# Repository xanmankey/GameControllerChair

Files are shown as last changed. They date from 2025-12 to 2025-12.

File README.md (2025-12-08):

# "Gaming" Chair

So we decided to build a gaming chair... and by that we mean a chair that you can use to play video games!

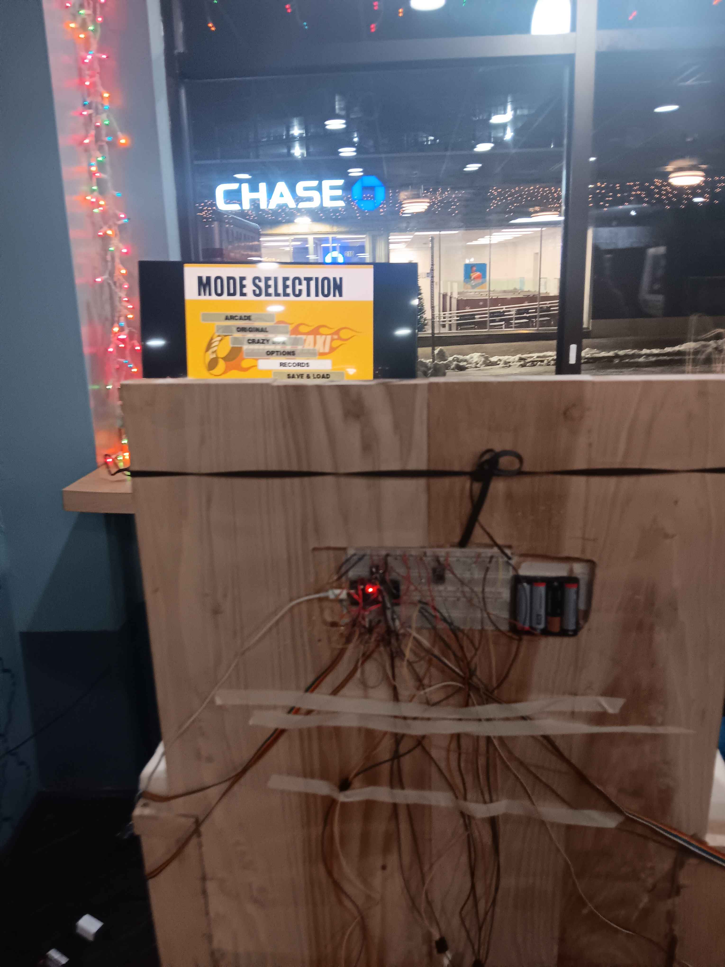
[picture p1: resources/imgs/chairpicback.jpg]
Back of the chair, set up to play Crazy Taxi


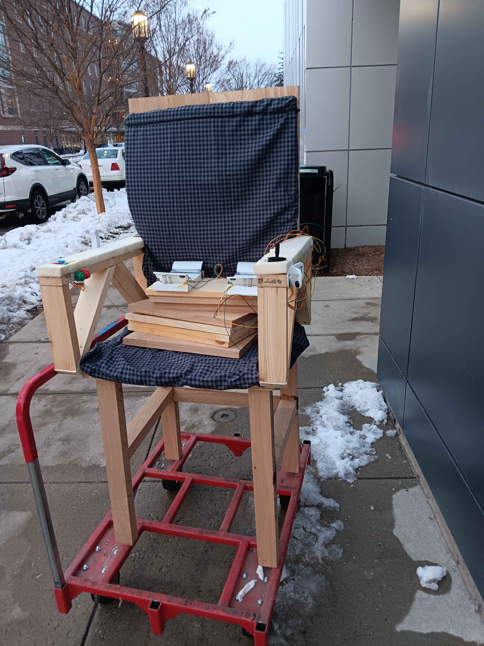
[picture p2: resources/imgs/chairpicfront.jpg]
Front of the chair; we will definitely be installing wheels, the cart was NOT the play


Below you can find a quick writeup on the components of our chair, as well as the BOM in case you want to build a "gaming" chair yourself or adapt an existing chair into one.

## Woods

Our chair is 29.5" x 23.5" x 57"; it's more of a gaming THRONE than a chair now that I think about it.

For the legs, we fashioned 7 pieces of about 2.5" x 2" x 24" and cut down 3 of them, domino jointing and woodgluing them horizontally to the other 4 legs for support (we left the front open so a wood support piece wouldn't interfere with dangling legs).

For the seat (22" x 21.5" x 1") and the back (24" x 1" x 32") we lucked out and happened to find pieces that mostly fit; we just had to do a bit of woodgluing and planing.

For the arms, the goal was to make triangle supports and domino joint/glue them to the back so that the triangle joints could be glued down to the seat for extra support; we mismeasured and so we had to make extension pieces to the side of the seat to provide extra support for the arms.

For placing the electronics, we drilled holes for the wires, chiseled out a place for the joystick (left arm) and buttons (right arm) and hand-routed into the back of the chair for a place for all the electronics.

## 3D Designs

There are currently 3 primary 3D designs that we used:

- The start lever
- [Left and right triggers](resources/models/TriggerButtons.f3d)
- [The foot pedals](resources/models/FootPedal.f3d)

Those designs can be found in the `resources/models` directory.

We also tried to make a box for cable management, but it didn't fit on the build plate of any of the printers that we had access to and so we ended up with a chair that 29 people (and counting) have said looks like an electric chair.

## Fabrics

We started to do upholstery, but ultimately decided to scrap it before the Purdue Hackers showcase due to time constraints; instead, we wrapped our foam and sewed in velcro, as well as stapling velcro to the back and the seat so the foam cushioning could be attached.

## Electrical

We bought a bunch of braided ribbon cable for the project; while this was good in terms of flexibility, it made soldering and wiring a bit of a nightmare. I've lost count of the number of solder joints that have broken at this point (mostly due to transport). We used an ESP32 microcontroller for the controller itself, analog hall effect sensors rigged with magnets that move closer to the sensor for the triggers and footpedals, and just attached the wires opposite each other for the start lever so they contact on pulling the lever. We battery-powered all the sensors which is probably unnecessary (you can probably get away with using 3v3V and stepping it up to 5V using a booster), but it's kinda funny so we kept it.

In terms of the electrical components we ended up using:

- Arcade buttons: https://a.co/d/8YRFZ9m
- Analog hall effect sensors: https://a.co/d/5u7OO93
- ESP32 microcontroller: https://a.co/d/g4PPseC
- Analog joystick: https://www.adafruit.com/product/3102
- Miniboost: https://www.adafruit.com/product/4654
- 6x Magnets: https://www.adafruit.com/product/9

## Programming

We were initially going to be using Bluetooth, but realized that there wasn't any point with all the wires we had anyway and so we migrated to communicating over USB serial (src/main.cpp) with a python script (src/controller.py) that uses the vgamepad library to emulate an xbox360 controller.

## Next Steps

We have commitments from people to play Dark Souls, Celeste, Cuphead, Silksong and various other games with the chair, so we want to make sure it's a polished gameplay experience. We plan on reworking the pedals, since the current solution has too much spring tension and is awkward to rest your feet on, as well as cleaning up some of the electrical and either upholstering or spray painting the chair (some kind of design work).

## Contributions

Thanks to @Benjamin for his help with the woodworking and electronics, to @Soham for his help with the electronics and 3D design and to @Grace for her help with soldering. Huge thank you to @PurdueHackers for funding this project and for organizing an awesome event for us to show it off and to @BechtelInnovationDesignCenter for helping us with woods and electronics and allowing us to borrow the tools needed to make this project a reality.

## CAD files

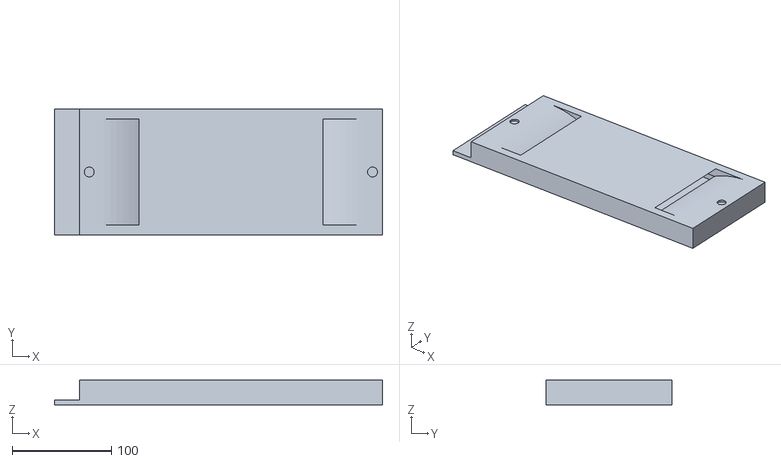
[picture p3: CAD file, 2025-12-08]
resources/models/PedalBase.stl
329.8 x 127.0 x 25.0

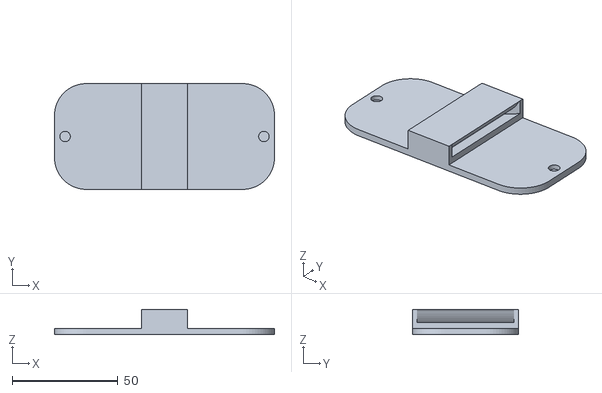
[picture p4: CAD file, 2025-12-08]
resources/models/TriggerBody.stl
104.0 x 50.0 x 12.0

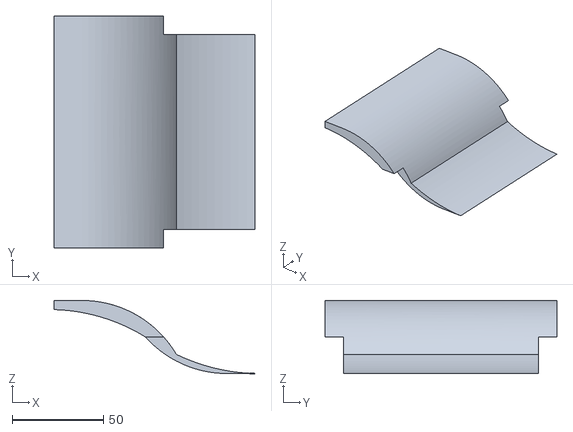
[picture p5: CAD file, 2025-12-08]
resources/models/MinusPedal.stl
109.9 x 127.0 x 40.0

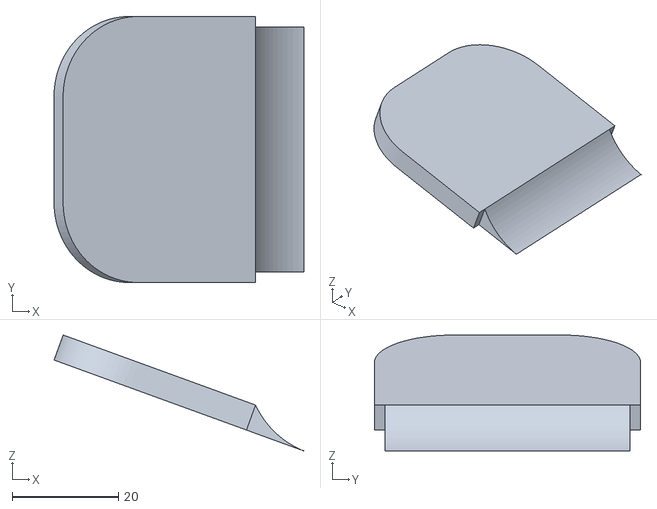
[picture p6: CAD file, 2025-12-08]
resources/models/LT.stl
47.0 x 50.0 x 21.8

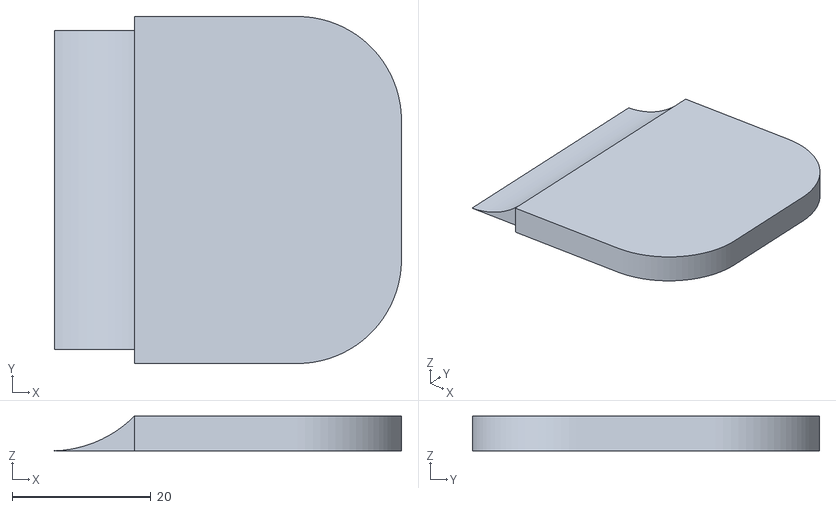
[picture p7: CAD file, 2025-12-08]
resources/models/RT.stl
50.0 x 50.0 x 5.00

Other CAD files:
resources/models/PlusPedal.stl
resources/models/FootPedal.f3d
resources/models/TriggerButtons.f3d

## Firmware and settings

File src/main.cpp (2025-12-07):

#include <Arduino.h>

// =======================
// PIN DEFINITIONS
// =======================
#define A GPIO_NUM_18
#define B GPIO_NUM_19
#define X GPIO_NUM_22
#define Y GPIO_NUM_23
#define LB GPIO_NUM_27
#define RB GPIO_NUM_4
#define START GPIO_NUM_21 

#define PEDAL_UP    GPIO_NUM_26
#define PEDAL_DOWN  GPIO_NUM_25
#define PEDAL_LEFT  GPIO_NUM_36 // was 14, changed due to weird analog glitch with lb and rb
#define PEDAL_RIGHT GPIO_NUM_32

#define CSTICK_X    GPIO_NUM_15 
#define CSTICK_Y    GPIO_NUM_33

#define LT GPIO_NUM_34
#define RT GPIO_NUM_35

// =======================
// CALIBRATION (Adjusted for Feet-On-Pedals)
// =======================

// --- PEDAL RIGHT (Active Low) ---
// Log: Rest ~1822, Max Press ~1703. Short range (~120).
// Drift seen: Positive 0.25 (meaning value dropped below 1800).
// New Rest: 1760 (Pushing threshold lower to ignore foot weight)
#define RIGHT_REST 1760 
#define RIGHT_MAX  1710 

// --- PEDAL LEFT (Active High) ---
// Log: Rest ~2080.
// New Rest: 2200 (Raised to ignore foot weight)
#define LEFT_REST 2200  
#define LEFT_MAX  2800

// --- PEDAL UP (Active High) ---
// Log: Rest ~1983.
// New Rest: 2100 (Raised to ignore foot weight)
#define UP_REST   2050  
#define UP_MAX    2400  

// --- PEDAL DOWN (Active High) ---
// Log: Rest ~1920.
// Drift seen: Negative 0.08 (meaning value went above 2000).
// New Rest: 2100 (Raised to ignore foot weight)
#define DOWN_REST 2050  
#define DOWN_MAX  2400

// --- JOYSTICK & TRIGGERS ---
#define JOY_CENTER 1850 
#define JOY_DEADZONE 250
#define JOY_MIN 0
#define JOY_MAX 4095

#define LT_MIN 2160  
#define LT_MAX 2750
#define RT_MIN 2160
#define RT_MAX 2800

#define TARGET_MAX 255

// =======================
// VARIABLES
// =======================
unsigned long lastLoopTime = 0;
const int loopInterval = 10; 
int prevStartReading = -1;       
bool virtualStartButtonState = false; 
unsigned long startButtonTimer = 0;   
const int startButtonDuration = 100;  

void setup() {
  Serial.begin(115200);

  // Buttons
  pinMode(A, INPUT_PULLDOWN);
  pinMode(B, INPUT_PULLDOWN);
  pinMode(X, INPUT_PULLDOWN);
  pinMode(Y, INPUT_PULLDOWN);
  pinMode(LB, INPUT_PULLDOWN);
  pinMode(RB, INPUT_PULLDOWN);
  pinMode(START, INPUT_PULLDOWN);

  // Pedals
  pinMode(PEDAL_UP, INPUT);
  pinMode(PEDAL_DOWN, INPUT);
  pinMode(PEDAL_LEFT, INPUT);
  pinMode(PEDAL_RIGHT, INPUT);

  // C-Stick & Triggers
  pinMode(CSTICK_X, INPUT);
  pinMode(CSTICK_Y, INPUT);
  pinMode(LT, INPUT);
  pinMode(RT, INPUT);
}

// Helper: Active High Mapping (Value goes UP)
int mapActiveHigh(int val, int rest, int max_val) {
    if (val < rest) return 0; // Deadzone
    int mapped = map(val, rest, max_val, 0, 127);
    return constrain(mapped, 0, 127);
}

// Helper: Active Low Mapping (Value goes DOWN) - Specifically for Right Pedal
int mapActiveLow(int val, int rest, int max_val) {
    if (val > rest) return 0; // Deadzone (Value is higher than threshold)
    // Map from Rest(High) -> Max(Low) to 0 -> 127
    int mapped = map(val, rest, max_val, 0, 127);
    return constrain(mapped, 0, 127);
}

int mapJoystick(int val) {
    int centered = val - JOY_CENTER;
    if (abs(centered) < JOY_DEADZONE) return 0;
    int result = 0;
    if (centered > 0) result = map(centered, JOY_DEADZONE, (JOY_MAX - JOY_CENTER), 0, 127);
    else result = map(centered, -JOY_DEADZONE, -(JOY_CENTER - JOY_MIN), 0, -127);
    return constrain(result, -127, 127);
}

int mapTrigger(int val, int min_t, int max_t) {
    if (val < min_t) return 0;
    long mapped = map(val, min_t, max_t, 0, TARGET_MAX);
    return constrain(mapped, 0, TARGET_MAX);
}

void loop() {
  unsigned long currentMillis = millis();

  if (currentMillis - lastLoopTime >= loopInterval) {
    lastLoopTime = currentMillis;

    // --- START BUTTON ---
    int currentStartReading = digitalRead(START);
    if (currentStartReading != prevStartReading) {
      if (prevStartReading != -1) { 
        virtualStartButtonState = true; 
        startButtonTimer = currentMillis; 
      }
      prevStartReading = currentStartReading; 
    }
    if (virtualStartButtonState && (currentMillis - startButtonTimer > startButtonDuration)) {
      virtualStartButtonState = false; 
    }

    // --- BUTTONS ---
    int b_a = digitalRead(A);
    int b_b = digitalRead(B);
    int b_x = digitalRead(X);
    int b_y = digitalRead(Y);
    int b_lb = digitalRead(LB);
    int b_rb = digitalRead(RB);

    // --- PEDALS ---
    int valRight = mapActiveLow(analogRead(PEDAL_RIGHT), RIGHT_REST, RIGHT_MAX);
    int valLeft  = mapActiveHigh(analogRead(PEDAL_LEFT), LEFT_REST, LEFT_MAX);
    int valUp    = mapActiveHigh(analogRead(PEDAL_UP), UP_REST, UP_MAX);
    int valDown  = mapActiveHigh(analogRead(PEDAL_DOWN), DOWN_REST, DOWN_MAX);

    // Combine into Axes
    int lx = valRight - valLeft; 
    int ly = valUp - valDown;

    // --- C-STICK ---
    int cx = mapJoystick(analogRead(CSTICK_X));
    // int cx = analogRead(CSTICK_X);
    int cy = mapJoystick(analogRead(CSTICK_Y));
    // int cy = analogRead(CSTICK_Y); 

    // --- TRIGGERS ---
    int trig_l = mapTrigger(analogRead(LT), LT_MIN, LT_MAX);
    int trig_r = mapTrigger(analogRead(RT), RT_MIN, RT_MAX);

    // Serial.println("CX: " + String(cx) + " CY: " + String(cy));
    // --- SEND DATA ---
    Serial.printf("%d,%d,%d,%d,%d,%d,%d,%d,%d,%d,%d,%d,%d\n", 
      virtualStartButtonState, b_a, b_b, b_x, b_y, b_lb, b_rb, lx, ly, cy, cx, trig_l, trig_r);
  }
}

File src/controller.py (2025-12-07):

import serial
import vgamepad as vg
import time

# UPDATE PORT IF NEEDED
SERIAL_PORT = "/dev/ttyUSB0"
BAUD_RATE = 115200
NUM_INPUTS = 13


def main():
    try:
        ser = serial.Serial(SERIAL_PORT, BAUD_RATE, timeout=0.1)
        print(f"Connected to {SERIAL_PORT}")
    except Exception as e:
        print(f"Error: {e}")
        return

    gamepad = vg.VX360Gamepad()
    print("Bridge running...")

    try:
        while True:
            line = ser.readline().decode("utf-8", errors="ignore").strip()
            if not line:
                continue

            try:
                data = [int(val) for val in line.split(",")]
                if len(data) != NUM_INPUTS:
                    continue

                # Unpack all 13 values
                (start, a, b, x, y, lb, rb, lx, ly, cy, cx, lt, rt) = data

                # Buttons
                if a:
                    gamepad.press_button(button=vg.XUSB_BUTTON.XUSB_GAMEPAD_A)
                else:
                    gamepad.release_button(button=vg.XUSB_BUTTON.XUSB_GAMEPAD_A)
                if b:
                    gamepad.press_button(button=vg.XUSB_BUTTON.XUSB_GAMEPAD_B)
                else:
                    gamepad.release_button(button=vg.XUSB_BUTTON.XUSB_GAMEPAD_B)
                if x:
                    gamepad.press_button(button=vg.XUSB_BUTTON.XUSB_GAMEPAD_X)
                else:
                    gamepad.release_button(button=vg.XUSB_BUTTON.XUSB_GAMEPAD_X)
                if y:
                    gamepad.press_button(button=vg.XUSB_BUTTON.XUSB_GAMEPAD_Y)
                else:
                    gamepad.release_button(button=vg.XUSB_BUTTON.XUSB_GAMEPAD_Y)
                if lb:
                    gamepad.press_button(
                        button=vg.XUSB_BUTTON.XUSB_GAMEPAD_LEFT_SHOULDER
                    )
                else:
                    gamepad.release_button(
                        button=vg.XUSB_BUTTON.XUSB_GAMEPAD_LEFT_SHOULDER
                    )
                if rb:
                    gamepad.press_button(
                        button=vg.XUSB_BUTTON.XUSB_GAMEPAD_RIGHT_SHOULDER
                    )
                else:
                    gamepad.release_button(
                        button=vg.XUSB_BUTTON.XUSB_GAMEPAD_RIGHT_SHOULDER
                    )
                if start:
                    gamepad.press_button(button=vg.XUSB_BUTTON.XUSB_GAMEPAD_START)
                else:
                    gamepad.release_button(button=vg.XUSB_BUTTON.XUSB_GAMEPAD_START)

                # Left Stick (Pedals)
                gamepad.left_joystick(x_value=lx * 256, y_value=ly * 256)

                # Right Stick (C-Stick) - NOW USING CX AND CY
                gamepad.right_joystick(x_value=cx * 256, y_value=cy * 256)

                # Triggers
                gamepad.left_trigger(value=lt)
                gamepad.right_trigger(value=rt)

                gamepad.update()

            except ValueError:
                pass

    except KeyboardInterrupt:
        ser.close()


if __name__ == "__main__":
    main()

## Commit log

2025-12-06 got buttons to work, axes still dont work
2025-12-08 initial readme writeup
    [FootPedal.f3d, LT.stl, MinusPedal.stl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]
